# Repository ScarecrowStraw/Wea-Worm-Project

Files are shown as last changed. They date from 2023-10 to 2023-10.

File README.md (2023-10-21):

# iFaw-Project

Weather Station and Faw Counting 

## Table of Contents 

1. [System Overview](#overview)

2. [System Installation](#installation)

    2.1. [Hardware](#hardware)

    2.2. [Software](#software)

      2.2.1. [Node-RED](#node-red)

      2.2.2. [MongoDB Client](#mongodb-client)

      2.2.3. [FawPredict](#fawpredict)

3. [Citation](#citation)

4. [Acknowledgements](#acknowledgements)

# 1. System Overview 

Pending ...
# 2. System Installation 
## 2.1. Hardware 

- ESP32
- GY1145
- Weather Station (DF Robot)
- Faw Counter (custom design)

### Install:
1. Install ESP32 Add-on in Arduino IDE. 

  - In Arduino IDE, go to File > Preferences. <br>
  - Copy and paste the following line to the Additional Boards Manager URLs field:<br>
  <https://raw.githubusercontent.com/espressif/arduino-esp32/gh-pages/package_esp32_index.json> <br>
  - Open the Boards Manager:<br>
    + You can go to Tools > Board > Boards Manager…<br>
    + Search for ESP32 and press the install button for esp32 by Arduino.<br>

2. Add SoftwareSerial Lib:<br>
  - In the menu bar, select Sketchs > Include Library > Add .Zip Library...<br>
  - Select espsoftwareserial-main.zip in Libs folder.<br>

3. Add GY1145 Libs:<br>
  - In the menu bar, select Tools > Manage Libraries…<br>
  - Search "Adafruit SI1145" and install.<br>

4. Wifi Lib:<br>
  - The PubSubClient library provides a client for doing simple publish/subscribe messaging with a server that supports MQTT (basically allows your ESP32 to talk with Node-RED).<br>
[Click here to dowload Libs](https://github.com/knolleary/pubsubclient/archive/master.zip) <br>
You should have a .zip folder in your Downloads folder
Unzip the .zip folder and you should get pubsubclient-master folder. <br>
Rename your folder from pubsubclient-master to pubsubclient. <br>
  - In the menu bar, select Sketchs > Include Library > Add .Zip Library...<br>
  - Select pubsubclient.zip.<br>
### Hardware Settings:<br>
| ESP32 | Weather | GY1145 | Counter|
| --- | --- | --- | ---|
| 5V  | 5V |  x | 5V |
| 3.3V  | x |  x | Vin |
| GND  | GND | GND | GND |
| TX2  | RX |  x | x  |
| RX2  | TX | x | x |
| SCL  | x | SCL | x |
| SDA  | x | SDA | x |
| GPIO33  | x | x | OUT |

### Upload code for ESP32: weatherv6

## 2.2. Software 

### 2.2.1. Node-RED 

1. Install Node-RED: [Click here](https://nodered.org/docs/getting-started/local)
2. Import [flows.json](./Software/Node-RED/flows.json) to Node-RED
3. Open terminal: Run command: node-red and open link local server.
   
### 2.2.2. MongoDB Client 

1. `cd Software/MongoDBClient`
2. `pip install -r requirements.txt`

### 2.2.3. FawPredict 

### Setup

1. Clone repo
2. `cd Software/FAWpredict`
3. `pip install -r requirements.txt`
4. Copy .env.example into .env and fill in the API key

### How to run

Open the terminal and type
  
    python FAWPredict.py --mode [SELECT_MODE] --location [SELECT_LOCATION] --date [SELECT_DATE] --age [SELECT_AGE]
    
- [SELECT_MODE]: `regression` mode or `lookup` mode
- [SELECT_LOCATION]: location to analyze (for example: Hanoi)
- [SELECT_DATE]: format: yyyy-mm-dd (Example: 2022-04-01)
- [SELECT_AGE]: a number from 0-8 represent for development stages of worm
```   
0: egg
1: first instar
2: second instar
3: third instar
4: fourth instar
5: fifth instar
6: sixth instar
7: larval stage
8: adult stage
```

## 3.Citation 

## 4.Acknowledgements

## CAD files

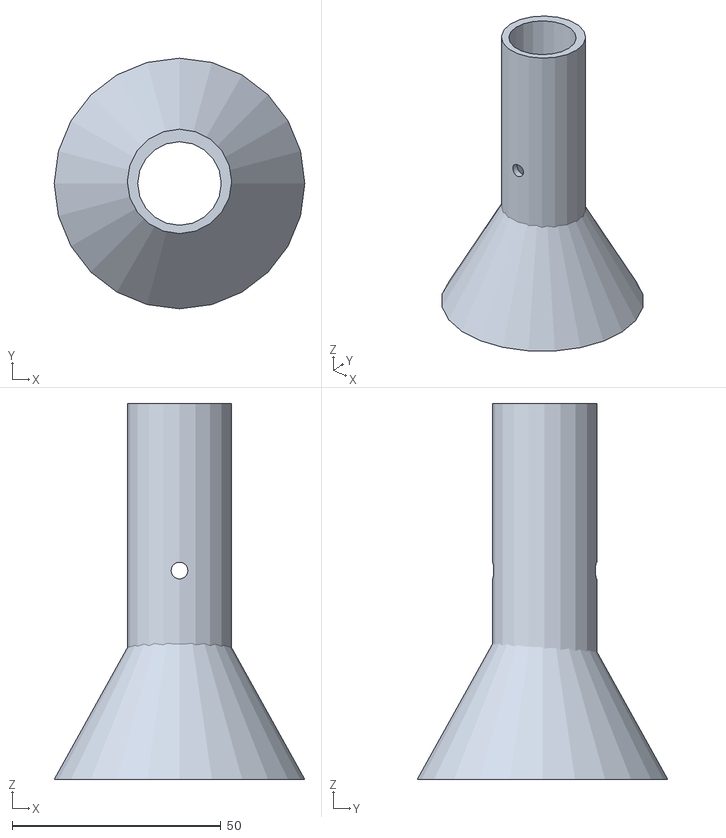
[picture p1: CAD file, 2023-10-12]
Hardware/worncount.stl
60.0 x 60.0 x 90.0

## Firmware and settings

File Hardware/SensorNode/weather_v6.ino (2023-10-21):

#include <WiFi.h> // wifi library
#include <PubSubClient.h> // server and client (Lib: Pubsubclient by Nick)
#include <SoftwareSerial.h> // read buffer weather (Lib: espsoftwareserial)
#include <string.h> 
#include "Adafruit_SI1145.h" // read light sensor (Lib: Adafruit_SI1145)

//---------------------------------
// light sensor
Adafruit_SI1145 uv = Adafruit_SI1145();

// weaather connection
SoftwareSerial mySerial(16, 17); // RX, TX
long lastMsg = 0;
char msg[50];
int value = 0;
char databuffer[35];


// wifi connection
const char* ssid = "Fatlab";
const char* password = "12345678@!";

// Add your MQTT Broker IP address, example:
//const char* mqtt_server = "192.168.1.144";
const char* mqtt_server = "192.168.1.113";
WiFiClient espClient;
PubSubClient client(espClient);

// FAW counter
volatile int IRQcount;
int pin = 33;
int pin_irq = 33; //IRQ that matches to pin 33

// Global variable
const int delaySendData = 1000; 
float averageHumid = 75.0;
float currentHumid;

float averageTemprature = 25.0;
float currentTemprature;

float averageBarPress = 1048.100;
//-------------------------------------------------------
// Setup before ru
void setup()
{
  Serial.begin(9600);
  attachInterrupt(pin_irq, IRQcounter, FALLING); // HIGHT or FALLING

  setup_wifi();
  client.setServer(mqtt_server, 1883);
  if (! uv.begin()) {
    Serial.println("Didn't find Si1145");
    while (1);
  }
  mySerial.begin(9600); 
}
//=========================***==============================
// Main programe
void loop()
{ 
  delay(1000); // delay for warming up
  // Enable for FAW counting interupt
  attachInterrupt(pin_irq, IRQcounter, FALLING); // HIGHT or FALLING

  // Connect to the client (weather station?)
  if (!client.connected()) {
    reconnect();
  }
  client.loop(); // connected
  getBuffer(); // read buffer


  ReadAndPublishData(); // read data and publish data to server
 

  delay(1000);
}
//=======================================================
void setup_wifi() {
  delay(10);
  // We start by connecting to a WiFi network
  Serial.println();
  Serial.print("Connecting to ");
  Serial.println(ssid);

  WiFi.begin(ssid, password);

  while (WiFi.status() != WL_CONNECTED) {
    delay(500);
    Serial.print(".");
  }

  Serial.println("");
  Serial.println("WiFi connected");
  Serial.println("IP address: ");
  Serial.println(WiFi.localIP());
}
//-------------------------------------------------------
void reconnect() {
  // Loop until we're reconnected
  while (!client.connected()) {
    Serial.print("Attempting MQTT connection...");
    // Attempt to connect
    if (client.connect("ESP8266Client")) {
      Serial.println("connected");
      // Subscribe
      client.subscribe("esp32/output");
    } else {
      Serial.print("failed, rc=");
      Serial.print(client.state());
      Serial.println(" try again in 5 seconds");
      // Wait 5 seconds before retrying
      delay(5000);
    }
  }
}

//-------------------------------------------------------
void getBuffer()      //Get weather status data
{
  int index;
  for (index = 0; index < 35; index ++)
  {
    if (mySerial.available())
    {
      databuffer[index] = mySerial.read();
      if (databuffer[0] != 'c')
      {
        index = -1;
      }
    }
    else
    {
      index --;
    }
  }
}
//-------------------------------------------------------
int transCharToInt(char *_buffer, int _start, int _stop)                             //char to int）
{
  int _index;
  int result = 0;
  int num = _stop - _start + 1;
  int _temp[num];
  for (_index = _start; _index <= _stop; _index ++)
  {
    _temp[_index - _start] = _buffer[_index] - '0';
    result = 10 * result + _temp[_index - _start];
  }
  return result;
}
//-------------------------------------------------------
int transCharToInt_T(char *_buffer)
{
  int result = 0;
  if (_buffer[13] == '-') {
    result = 0 - (((_buffer[14] - '0') * 10) + (_buffer[15] - '0'));
  }
  else {
    result = ((_buffer[13] - '0') * 100) + ((_buffer[14] - '0') * 10) + (_buffer[15] - '0');
  }
  return result;
}
//-------------------------------------------------------
int WindDirection()                                                                  //Wind Direction
{
  return transCharToInt(databuffer, 1, 3);
}
//-------------------------------------------------------
float WindSpeedAverage()                                                             //air Speed (1 minute)
{
  float temp;
  temp = 0.44704 * transCharToInt(databuffer, 5, 7);
  return temp;
}
//-------------------------------------------------------
float WindSpeedMax()                                                                 //Max air speed (5 minutes)
{
  float temp;
  temp = 0.44704 * transCharToInt(databuffer, 9, 11);
  return temp;
}
//-------------------------------------------------------
float Temperature()                                                                  //Temperature ("C")
{
  float temp;
  temp = (transCharToInt_T(databuffer) - 32.00) * 5.00 / 9.00;
  return temp;
}
//-------------------------------------------------------
float RainfallOneHour()                                                              //Rainfall (1 hour)
{
  float temp;
  temp = transCharToInt(databuffer, 17, 19) * 25.40 * 0.01;
  return temp;
}
//-------------------------------------------------------
float RainfallOneDay()                                                               //Rainfall (24 hours)
{
  float temp;
  temp = transCharToInt(databuffer, 21, 23) * 25.40 * 0.01;
  return temp;
}
//-------------------------------------------------------
float Humidity()                                                                       //Humidity
{
  float temp;
  temp = transCharToInt(databuffer, 25, 26);
  return temp;
}
//-------------------------------------------------------
float BarPressure()              //Barometric Pressure
{
  float temp;
  temp = transCharToInt(databuffer, 28, 32);
  return temp / 10.00;
  //delay(2000);
}
//-------------------------------------------------------
void IRQcounter() {
  detachInterrupt(pin_irq);
  IRQcount++;
  int n=1000;
  while (n>0){
    n--;
  }

}

//-------------------------------------------------------
void ReadAndPublishData(){
  float temperature = Temperature();
  if (temperature > 0 && temperature <= 50){
    //Serial.println(temperature);
    if ( abs(temperature-averageTemprature) >15){
      temperature = averageTemprature;
    }else{
      temperature = (currentTemprature + temperature)/2.0;
      currentTemprature = temperature;
      //averageHumid = currentHumid;
    }
      char tempString[8];
      dtostrf(temperature, 1, 2, tempString);
      client.publish("esp32/temperature", tempString);
      //delay(delaySendData);
      // Lưu previous temprature: lấy trung bình rồi mới gửi
      Serial.println("temprature");
      Serial.println(temperature);

  }

  float humid = Humidity();

  if (humid > 0 && humid <= 100){
    //Serial.println(humid);
    if ( abs(humid-averageHumid) >25){
      humid = averageHumid;
    }else{
      humid = (currentHumid + humid)/2.0;
      currentHumid = humid;
      //averageHumid = currentHumid;
    }
      char humidString[8];
      dtostrf(humid, 1, 2, humidString);
      client.publish("esp32/humidity", humidString);
      //delay(delaySendData);
      // Lưu previous temprature: lấy trung bình 2/3 gia tri truoc do rồi mới gửi
      Serial.println("humid");
      Serial.println(humid);
  }

  float windD = WindDirection();
  char windDString[8];
  dtostrf(windD, 1, 2, windDString);
  client.publish("esp32/winddirection", windDString);
    
  float windS = WindSpeedAverage();
  char windSString[8];
  dtostrf(windS, 1, 2, windSString);
  client.publish("esp32/windspeed", windSString);

  float rain1H = RainfallOneHour();
  char rain1HString[8];
  dtostrf(rain1H, 1, 2, rain1HString);
  client.publish("esp32/rain1H", rain1HString);


  float rain1D = RainfallOneDay();
  char rain1DString[8];
  dtostrf(rain1D, 1, 2, rain1DString);
  client.publish("esp32/rain1D", rain1DString);

  float barPress = BarPressure();
  if (barPress > 600 && barPress < 1100){
    barPress = (averageBarPress + barPress)/2.0;
    averageBarPress = barPress;
      char barPString[8];
      dtostrf(barPress, 1, 2, barPString);
      client.publish("esp32/barP", barPString);
  }
  
  float UVindex = uv.readUV();
  // the index is multiplied by 100 so to get the
  // integer index, divide by 100!
  UVindex /= 100.0; 
  
  float Vis = uv.readVisible();
  char VisString[8];
  dtostrf(Vis, 1, 2, VisString);
  client.publish("esp32/Vis", VisString);

  float IR = uv.readIR();
  char IRString[8];
  dtostrf(IR, 1, 2, IRString);
  client.publish("esp32/IR", IRString);

  float UV = uv.readUV();
  char UVString[8];
  dtostrf(UV, 1, 2, UVString);
  client.publish("esp32/UV", UVString);

  char countString[8];
  dtostrf(IRQcount, 1, 2, countString);
  client.publish("esp32/counter", countString);
  Serial.println("counter: ");
  Serial.println(IRQcount);
  //counter = 0;
}
//-------------------------------------------------------

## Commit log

2023-07-27 [Update] Arduino code
2023-08-30 [Clean code]
    [faw_data.csv, regression_data.csv, weather_data.csv]
